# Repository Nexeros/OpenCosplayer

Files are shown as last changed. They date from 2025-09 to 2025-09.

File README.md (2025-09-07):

# OpenCosplayer



An open-source platform for creating, sharing, and modifying 3D printable models, schematics, and code for robotic and intelligent cosplay exoskeletons.

---

## About The Project

Welcome to **OpenCosplayer**! This repository is a free human-made collection of resources for building advanced, intelligent, and semi-intelligent robotic skeletons for cosplay. Whether you're a maker, an engineer, or a cosplayer looking to bring your creations to the next level, you've come to the right place.

My goal is to provide a central hub for:
*   **3D Models:** Parametric and modular 3D printable parts for exoskeletons.
*   **Schematics:** Wiring diagrams and hardware plans for integrating electronics.
*   **Code:** Firmware and software to control motors, lights, and other interactive elements.

This project is built on the principle of open collaboration. Feel free to use, modify, and share your own versions of these designs!

## Getting Started

To get started with the project files, you will need access to certain tools and software.

*   **For 3D Models (.3mf, .step, .f3d):**
    *   A 3D printer and slicing software (e.g., PrusaSlicer, Cura).
    *   CAD software for viewing or modifying models (e.g., Autodesk Fusion 360, FreeCAD).
*   **For Schematics (.pdf, .sch):**
    *   A PDF viewer or electronics design software (e.g., KiCad, Eagle).
*   **For Code (.ino, .cpp):**
    *   An IDE compatible with your target microcontroller (e.g., Arduino IDE, PlatformIO).

### Installation

1.  Clone the repository to your local machine:
    ```sh
    git clone https://github.com/Nexeros/OpenCosplayer.git
    ```
2.  Navigate to the specific project folder you are interested in (e.g., `/models/arm_actuator_v1/`).
3.  Follow the instructions in that folder's `README.md` file for specific build details.

See the [open issues](https://github.com/Nexeros/OpenCosplayer/issues) for a full list of proposed features and known issues.

## Contributing

Contributions are what make the open-source community such an amazing place to learn, inspire, and create. Any contributions you make are **greatly appreciated**.

If you have a suggestion that would make this better, please fork the repo and create a pull request. You can also simply open an issue with the tag "enhancement".

1.  Fork the Project
2.  Create your Feature Branch (`git checkout -b feature/AmazingFeature`)
3.  Commit your Changes (`git commit -m 'Add some AmazingFeature'`)
4.  Push to the Branch (`git push origin feature/AmazingFeature`)
5.  Open a Pull Request

**Important:** Please note that all contributions to this project will be licensed under the same CC BY-NC-SA 4.0 license.

## License

This project is distributed under the **Creative Commons Attribution-NonCommercial-ShareAlike 4.0 International License**. See `LICENSE.md` for more information.

This means you are free to:
*   **Share** — copy and redistribute the material in any medium or format.
*   **Adapt** — remix, transform, and build upon the material.

Under the following terms:
*   **Attribution** — You must give appropriate credit.
*   **NonCommercial** — You may not use the material for commercial purposes.
*   **ShareAlike** — If you remix, transform, or build upon the material, you must distribute your contributions under the same license as the original.

## Contact
Maybe someday my mail will appear here

Project Link: [https://github.com/your-username/OpenCosplayer](https://github.com/Nexeros/OpenCosplayer)

## Acknowledgments

*   Maybe someday someone will appear here

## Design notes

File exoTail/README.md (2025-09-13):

# Project: Mechanical Exo-Tail

This folder contains all necessary files (3D models, etc.) to build a mechanical, segmented tail. The project was designed with modularity in mind and is available in two main versions.

obraz

---

## Project Versions

1.  **Inertial Version (Passive):** Simpler to build, requires no electronics. The tail moves naturally based on the wearer's body movement and inertia. Bearings ensure a smooth motion. This is a great starting point.
2.  **Motorized Version (Active):** A more advanced version where each segment (or selected segments) is controlled by servo motors. This allows for programmed movement sequences and remote control.

---

## Bill of Materials (BOM)

This list covers parts common to both versions. Additional components for the motorized version will be listed separately.

#### Non-Printed Parts (per segment):
*   **Self-Tapping Screw:** `2x` M3 (length 8-12 mm, **Important:** head diameter must be 6.8mm or less)
*   **Steel Rope:** `3x` 1,5mm (length 10cm times number of modules. **Not necessary for Inertial version, but can help to align tail**) [Recomended](https://www.leroymerlin.pl/produkty/linka-stalowa-nierdzewna-27-kg-1-5-mm-x-5-m-standers-89125636.html)
*   **PTFE tube:** `3x` 4mm (length 42mm times number of modules + 28mm for base module + 67mm for end module)
*   **Springs:** `4x` 15mm (recommended, max 30, min 10mm as you want to stiffen your tail) [Recomended](https://www.leroymerlin.pl/produkty/sprezyna-naciagowa-9-kg-7-x-30-x-1-mm-2-szt-standers-91007852.html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)

#### 3D Printed Parts (per segment):
*   `1x` spine_module.3mf
*   `4x` distancer.3mf
*   `1x` rubber_bushing.3mf

---

## Assembly Instructions (Inertial Version)

**Step 1: Prepare the Prints**
*   Ensure all parts are printed correctly. Remove all support material and clean up any holes, especially for the screws.

**Step 2: Connect the Segments**
*   Align `spine_module` over next `spine_module` at 90 degrees and slide in bearing hole, then align them so that the holes in both parts and the bearing line up perfectly.
*   Slide the `distancer`.

**Step 3: Secure the Connection**
*   Drive the `M3` self-tapping screws into the holes on the `distancer`. This will secure the entire joint by locking the pin in place. Do not overtighten, as this can damage the plastic.

**Step 4: Repeat the Process**
*   Repeat steps 2-4 for each subsequent segment until you achieve your desired tail length. Use a special `end_module.3mf` for the final segment.

**Step 7: Mount the Base**
*   Attach the first segment to the `base_module.3mf` with mounted `*_mount.3mf` (based on version), which is used to fasten the tail to a belt or harness.

**Step 8: Install ropes (not necessary for Inertial version)** 
*   Cut 4mm (1.7mm inner) PTFE tube and slide it into the holes in the segments.
*   Drag steel rope through segments, including `end_module.3mf` and `base_module.3mf`.
*   Lock with srews at ends and in segments you want.

**Step 9: Install springs**
*   Tension the springs and attach them to the mounting holes in the segments.
---

## Recommendations and Tips

#### 3D Printing Tips
*   **Material:** **PETG** or **ABS/ASA** are recommended over PLA for their superior strength and durability.
*   **Infill:** A minimum of **25-30%** is suggested to ensure adequate rigidity. For critical parts like the pins, consider increasing this to 50% or more.
*   **Layer Height:** 0.2 mm is a good balance between quality and print time.
*   **Supports:** Supports may be necessary depending on the model's orientation. Use tree supports if possible for easier removal.

#### Assembly Tips
*   **Test Fit:** Before final assembly, check that all parts fit together smoothly. Some light sanding may be required.
*   **Lubrication:** For even smoother movement, apply a small amount of silicone-based grease to the bearings and pins.
*   **Do Not Overtighten:** Self-tapping screws can easily strip the plastic. Tighten them gently until you feel resistance, and then stop.

---

*This project is a work in progress. Suggestions and improvements are welcome!*

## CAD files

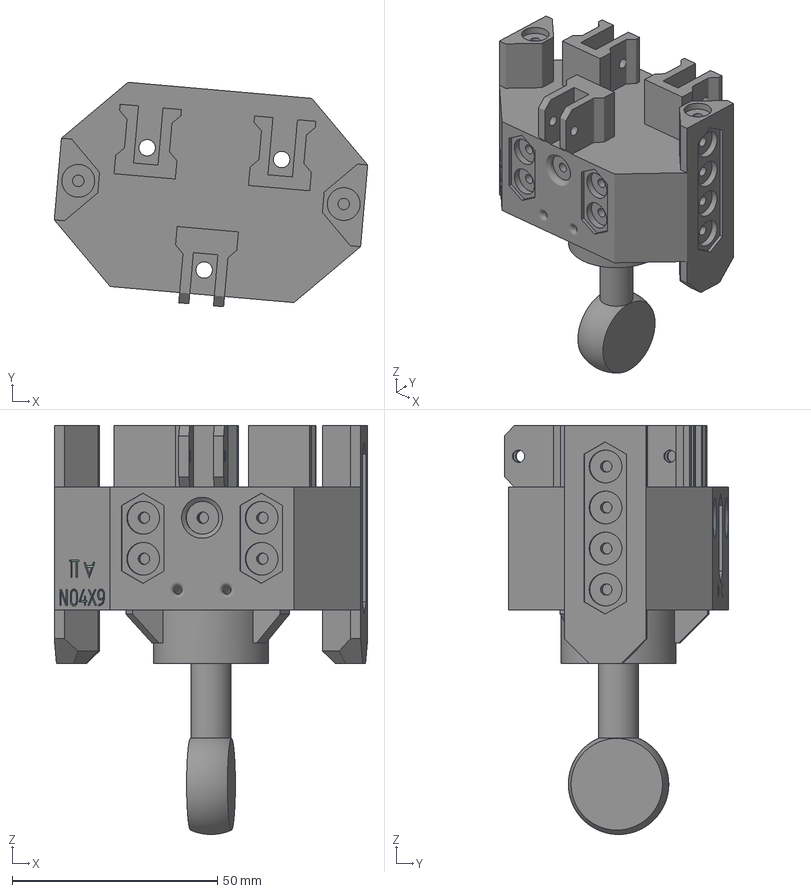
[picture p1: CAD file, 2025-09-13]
exoTail/base_module.3mf
76.5 x 54.7 x 99.8 mm

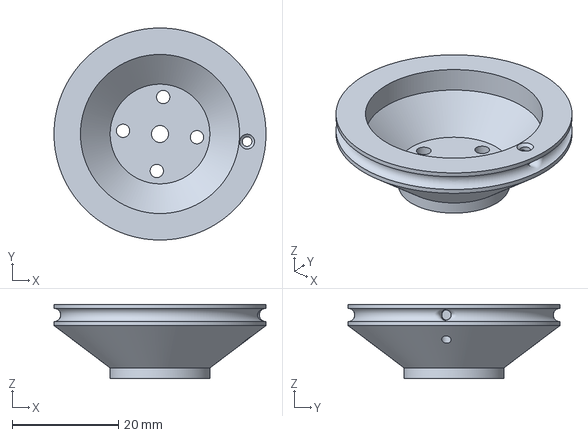
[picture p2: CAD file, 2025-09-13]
exoTail/tail_motorized/pulley.3mf
40.0 x 40.0 x 14.0 mm

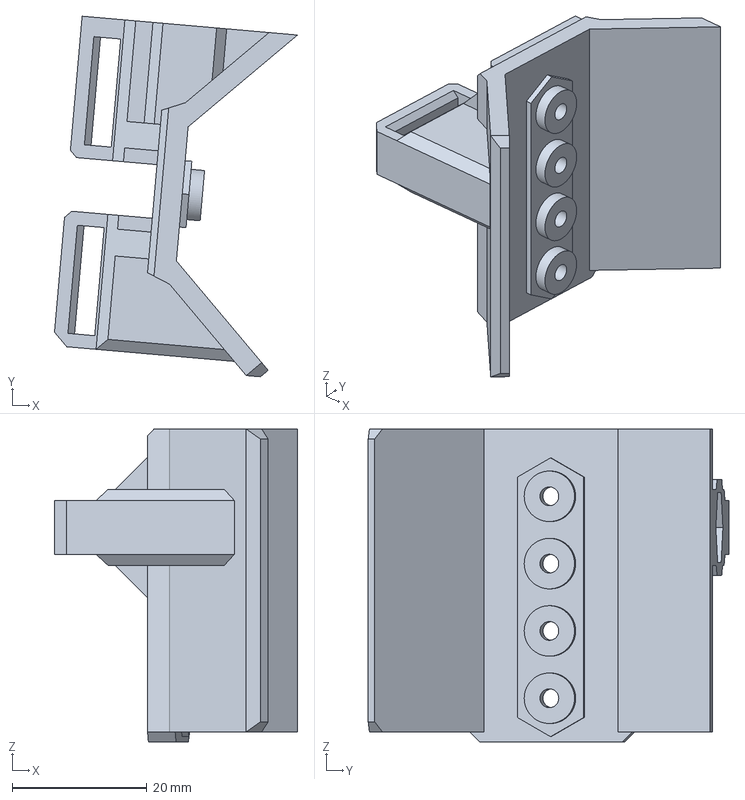
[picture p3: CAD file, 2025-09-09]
exoTail/side_mount.3mf
36.1 x 53.6 x 46.5 mm

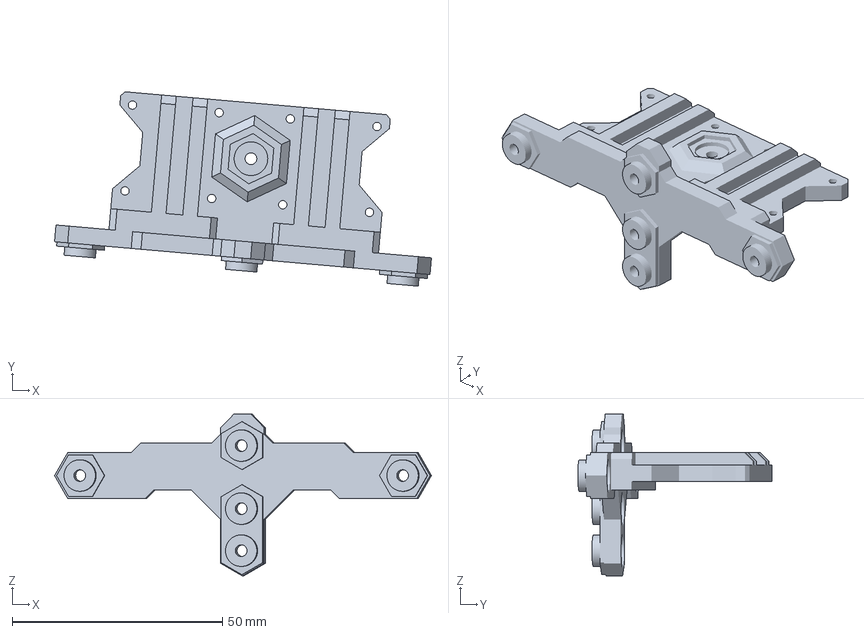
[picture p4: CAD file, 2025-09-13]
exoTail/tail_motorized/motor_mount_double.3mf
89.7 x 46.3 x 38.5 mm

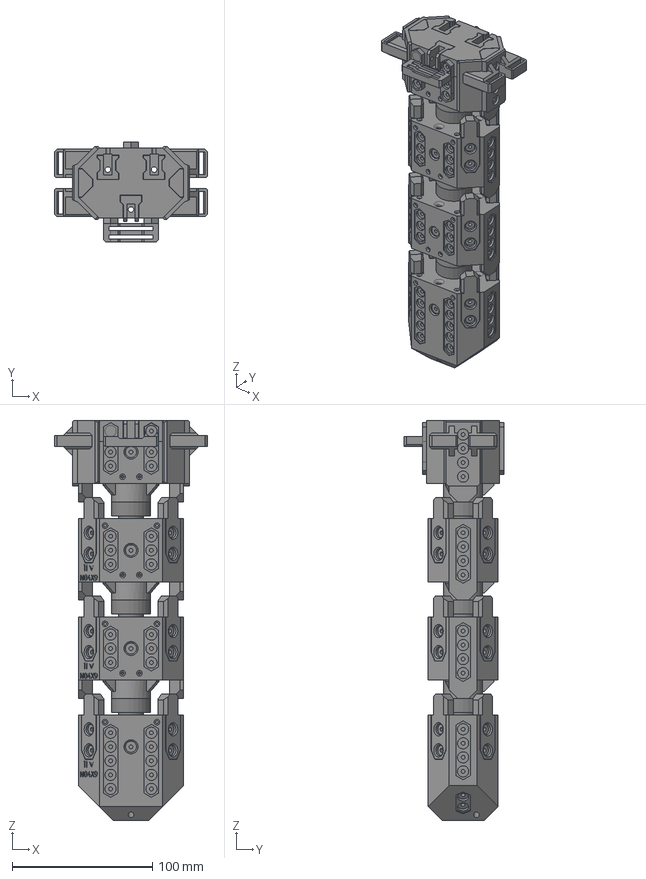
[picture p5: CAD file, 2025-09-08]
exoTail/exo_tail.step
109.2 x 71.0 x 285.0 mm
spine_module x 2
base_module_Inertial
693ZZ (1)
end_module

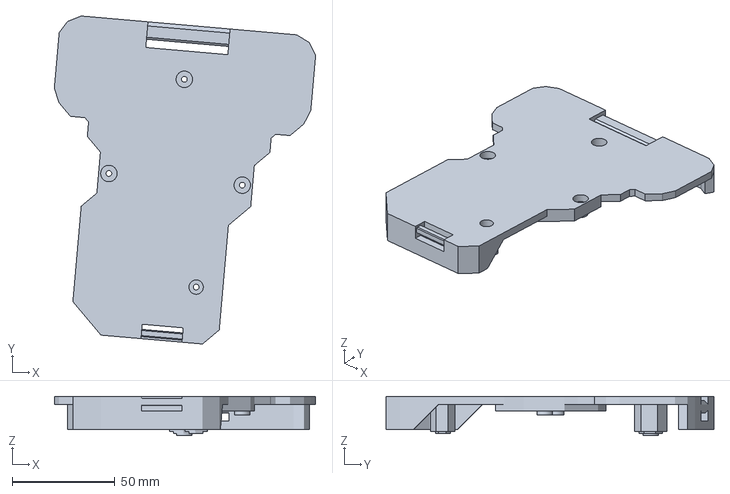
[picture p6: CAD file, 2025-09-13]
exoTail/tail_motorized/back_plate.3mf
126.9 x 159.2 x 19.1 mm

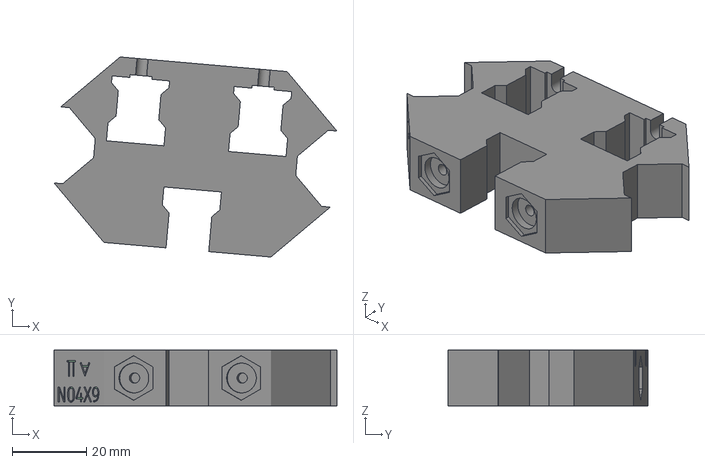
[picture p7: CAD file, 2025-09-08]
exoTail/base_module_part2.3mf
76.0 x 53.7 x 15.0 mm

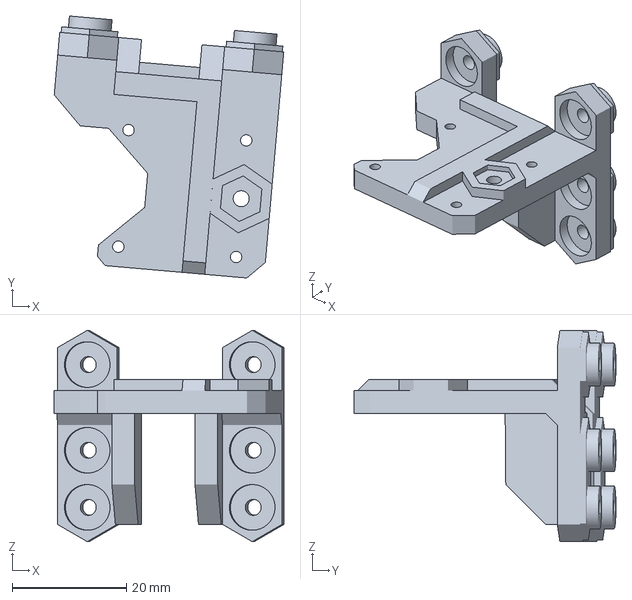
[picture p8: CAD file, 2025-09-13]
exoTail/tail_motorized/motor_mount_single.3mf
40.2 x 45.9 x 37.0 mm

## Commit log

2025-09-07 Create README for Mechanical Exo-Tail project
    Added comprehensive README for Mechanical Exo-Tail project, detailing project versions, bill of materials, assembly instructions, and tips for 3D printing and assembly.
2025-09-07 added STEP model
    unmotorized version ready step uploaded
    [exo_tail.step]
2025-09-07 added 3mfs for inertial
    [base_module.3mf, base_module_part2.3mf, bottom_mount.3mf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]
2025-09-07 Revise 3D parts and assembly steps in README.md
2025-09-08 fixed base module
    fixed base module to properly align bearings with holes
    [base_module.3mf, base_module_part2.3mf, exo_tail.step]
2025-09-08 fixed tolerances in base module part 2
    [base_module.3mf, base_module_part2.3mf, bottom_mount.3mf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]
2025-09-09 Revise PTFE tube length in README
2025-09-13 added 3mfs for motorizes and soem fixes
    [back_plate.3mf, motor_mount_double.3mf, motor_mount_single.3mf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]
2025-09-13 new base module 3mf compatible with motorized ver
    [base_module.3mf]
2025-09-13 Update README with recommended springs link
2025-09-13 Update screw head diameter requirement in README

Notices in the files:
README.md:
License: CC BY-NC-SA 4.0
